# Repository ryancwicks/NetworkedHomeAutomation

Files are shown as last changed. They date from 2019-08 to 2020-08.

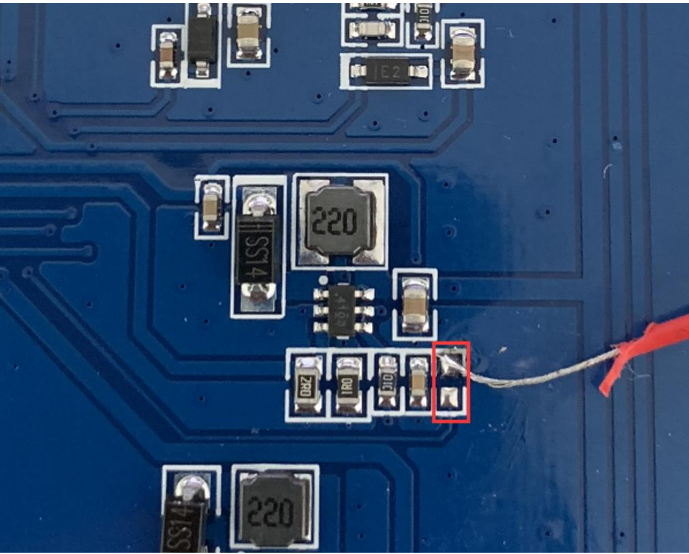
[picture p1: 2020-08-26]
images/waveshare-wire.png

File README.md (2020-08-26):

# Networked Home Automation

The repo contains all the setup files for a networked home automation system based on ESPHome, Node Red and a mix of networked switches and custom firmware.

The MQTT broker and NodeRed server run on a raspberry Pi Zero W (set up with Docker).

## Raspberry Pi Setup

The system has been set up using a Raspberry Pi B+. The Raspberry Pi OS Lite was used as the base. A 7" Waveshare LCD with a capacitive touch screen is used as the main interface.

Start raspi-config, set up the wifi, change the keyboard layout and setup openssh.

I set up the user using this page: 

https://www.raspberrypi.org/documentation/configuration/security.md

I also added a lxde:

https://raspberrytips.com/upgrade-raspbian-lite-to-desktop/

In raspi-config, set the system to autologin the gui.

The final piece to add is an install of Chromium. The current version of Firefox in the apt packages doesn't support kiosk mode.

```
sudo apt install chromium
```

Copy the script run_chrome_kiosk.sh to /home/<user> and set it executable.

Copy the node-mosquitto-service.service file to /etc/systemd/system

Copy the autostart file to ~/.config/lxsession/LXDE

Copy the contents of the nodeRED directory to the ~/docker-compose directory.

Install docker: 

```
curl -sSL https://get.docker.com | sh
sudo usermod -aG docker pi 
```

Reboot here, and then test docker:

```
docker run hello-world --rm
```

```
sudo apt-get install -y libffi-dev libssl-dev
sudo apt-get install -y python3 python3-pip
sudo apt-get remove python-configparser
```

setup docker compose:

```
sudo pip3 -v install docker-compose 
```

I also installed log2ram to prevent SD card wear:

https://mcuoneclipse.com/2019/04/01/log2ram-extending-sd-card-lifetime-for-raspberry-pi-lorawan-gateway/

Set up the gui to auto login under the system preference.

Set the screensaver to return a black screen after 1 minute.

## Resolution very low

Edit the /boot/config.txt file and ensure the following is set.

max_usb_current=1
hdmi_group=2
hdmi_mode=87
hdmi_cvt 1024 600 60 6 0 0 0
hdmi_drive=1

## Chrome doesn't work:

For some reason, I was getting an illegal instruction error when I tried to run chromium. Instead I installed Midori and changed the autostart command to 

```
midori -e Fullscreen -a http://google.com
```

## Set up the backlight:

This needs to be done manually. A wire needs to be run from Raspberry pi pin 20 to a SMD pad on the board.

The RPi pin is shown here:

![images/rpi-wire.png][RPi wire location]

The other end of the wire needs to be soldered here:

![images/waveshare-wire.png][Waveshare location]

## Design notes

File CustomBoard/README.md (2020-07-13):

# NetworkedHomeAutomation
Simple home automation setup using ESP32's as an MQTT client and a Raspberry Pi based MQTT broker.

# Testing the client:

Install the mosquitto app:

```bash
sudo snap install mosquitto
```

In one window, open the subscriber that listens for new devices:

```bash
mosquitto_sub -t "newDevice"
```

In another window, you can turn the device on and off with 

```bash
mosquitto_pub -t "LightSwitch/power" -m "1"
```

and

```bash
mosquitto_pub -t "lightSwitch/power" -m "0"
```

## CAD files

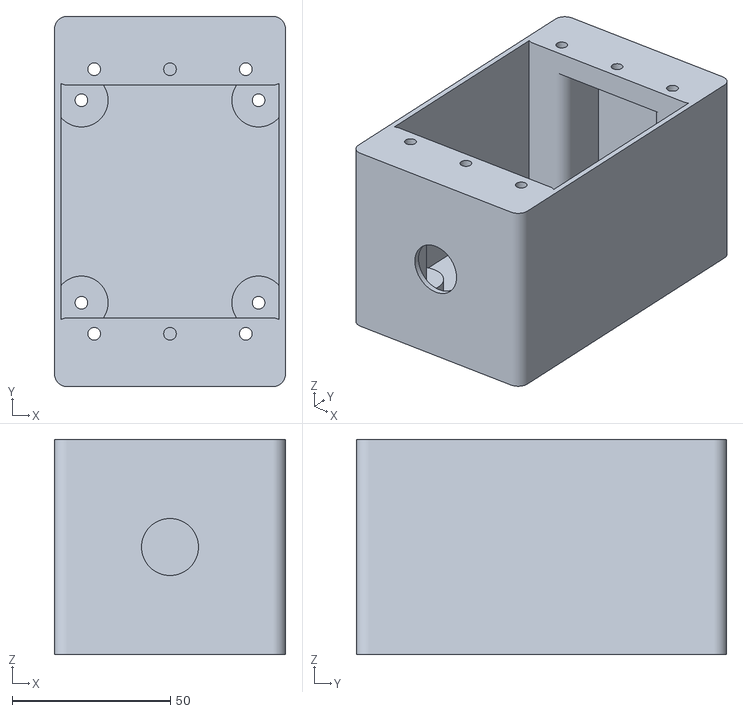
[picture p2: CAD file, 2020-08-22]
CustomBoard/PowerSwitchClient/HousingCAD/MainHousing.stl
73.0 x 117.0 x 68.0

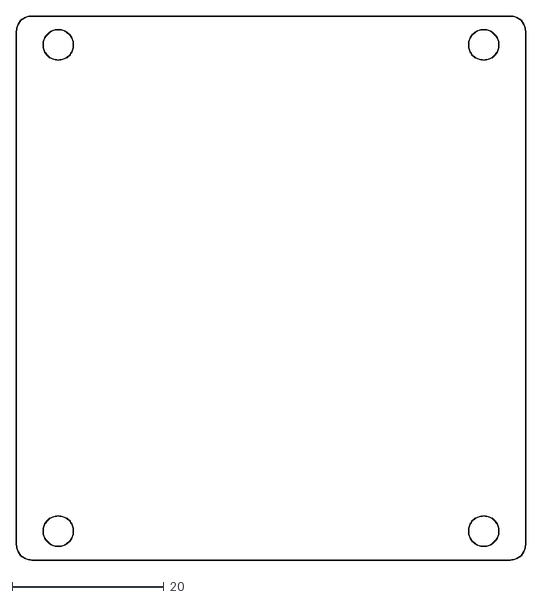
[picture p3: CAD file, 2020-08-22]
CustomBoard/PowerSwitchClient/HousingCAD/board_layout.dxf
67.0 x 71.6

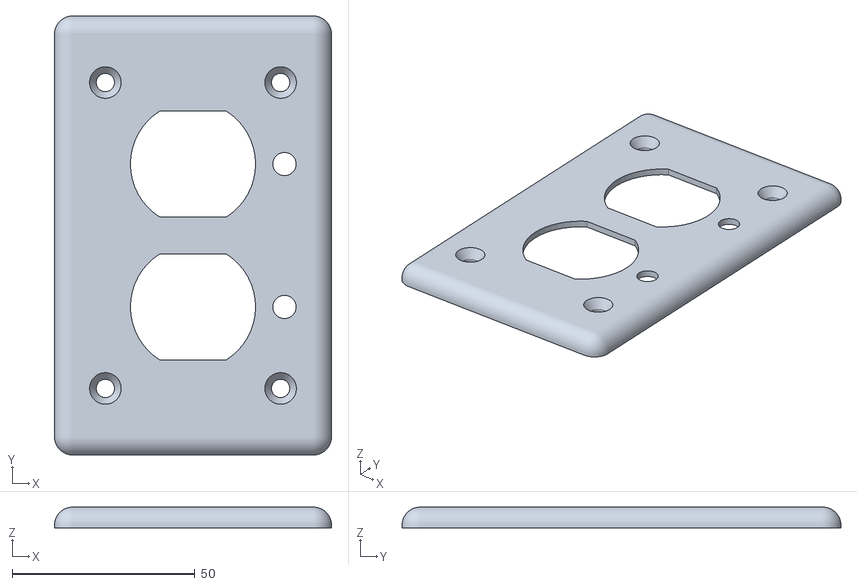
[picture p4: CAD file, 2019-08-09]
CustomBoard/PowerSwitchClient/HousingCAD/CoverPlate.stl
75.8 x 120.0 x 5.69

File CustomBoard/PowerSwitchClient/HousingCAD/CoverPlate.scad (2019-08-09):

$fn=50;

module screw_hole (height=1000) {
    diameter= 5;
    diameter_top = 8.7;
    union(){
        cylinder(r=diameter/2, h=height);
        cylinder(h=3, r1=diameter_top/2, r2=diameter/2);
    };
};

module base_plate () {
    width_total = 75.75;
    height_total = 120;
    thickness_total = 5.7;
    corner_radius = 5;
    back_inset_depth = 1.2;
    full_inset_depth = 2.5;
    clearance_hole_depth = full_inset_depth + 1.75;
    
    difference() {
        //main_body
       minkowski() {
           cube([width_total-2*corner_radius, height_total-2*corner_radius, 2*thickness_total-2*corner_radius], center=true);
           sphere(r=corner_radius, center=true);
       };
       
       //remove half of box
       translate([0, 0, -thickness_total]) cube([width_total, height_total,    thickness_total*2], center=true);
       
       //remove first inner layer (box rests on this surface
       translate([-(width_total-2 - corner_radius)/2, -(height_total- 2 - corner_radius)/2, -back_inset_depth/2]) minkowski() {
            cube([width_total - 2 - corner_radius, height_total - 2- corner_radius, back_inset_depth]);
            cylinder(r=corner_radius/2, h=back_inset_depth);
        };
        
        //remove inner layer (clearance for plug  components
       translate([-(width_total-5.2 - corner_radius)/2, -(height_total- 5.2 - corner_radius)/2, -full_inset_depth/2]) minkowski() {
           cube([width_total - 5.2 - corner_radius, height_total - 5.2- corner_radius, full_inset_depth]);
           cylinder(r=corner_radius/2, h=full_inset_depth);
       };
    };
    
    
};

module plug_hole(thickness) {
    height=29;
    diameter=34.2;
    
    difference() {
        cylinder(r=diameter/2, h=thickness, center=true);
        translate([0, height, 0]) cube([diameter, height, thickness], center=true);
        translate([0, -height, 0]) cube([diameter, height, thickness], center=true);
    };
};


led_hole = 6.35;
plate_hole_position = (10.1 + 68.0) / 4;
lateral_hole_position = (43 + 52.8)/4;
vertical_hole_position = (88.7 + 78.5)/4;
hole_positions = [ [lateral_hole_position, vertical_hole_position, 5.75], 
                  [-lateral_hole_position, vertical_hole_position, 5.75], 
                  [lateral_hole_position, -vertical_hole_position, 5.75], 
                  [-lateral_hole_position, -vertical_hole_position, 5.75] ];
difference() {
    union() {
        base_plate();
        for (pos = hole_positions) {
            translate([pos[0], pos[1],        
     1.3]) 
                cylinder(r=8.2/2, h=2*1.3);
        }
    };
    //socket holes
    translate([0, plate_hole_position, 0]) plug_hole(100);
    translate([0, -plate_hole_position, 0]) plug_hole(100);
    //led holes
    translate([25, plate_hole_position, 0]) cylinder(r=led_hole/2, h=100);
    translate([25, -plate_hole_position, 0]) cylinder(r=led_hole/2, h=100);
    for (pos = hole_positions) {
        translate(pos) rotate([180, 0, 0]) screw_hole();
        offset_pos = pos;
        //offset_pos[2] = 0.0012;
        translate(offset_pos) 
            cylinder(r=8.2, h=1.17);
    };
    for (pos = [[0, vertical_hole_position, 0], [0, -vertical_hole_position, 0]]) {
        translate (pos) cylinder(r=8.2/2, h=4.6);
    }
    
 };

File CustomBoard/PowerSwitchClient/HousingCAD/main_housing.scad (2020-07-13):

//**************************
// Defines
$fn=64;

width_total = 73;
height_total = 117;
thickness_total = 68;
wall_thickness = 4; //can fit an m6 machine nut

center= [width_total/2, height_total/2];

lateral_hole_position = (43 + 52.8)/4;
vertical_hole_position = (88.7 + 78.5)/4;

hole_positions = [ [lateral_hole_position + center[0], vertical_hole_position + center[1], 0], 
                  [-lateral_hole_position + center[0], vertical_hole_position + center[1], 0], 
                  [lateral_hole_position + center[0], -vertical_hole_position + center[1], 0], 
                  [-lateral_hole_position + center[0], -vertical_hole_position + center[1], 0] ];
   
board_xoff = 28;
board_yoff = 32;
board_hole_positions = [ [board_xoff + center[0], board_yoff + center[1], 0], 
                  [-board_xoff + center[0], board_yoff + center[1], 0], 
                  [board_xoff + center[0], -board_yoff + center[1], 0], 
                  [-board_xoff + center[0], -board_yoff + center[1], 0] ];
   
//Grommet clearance hole.
main_wire_hole_r = 18/2;

//For the #6 machine screws. May be different thread forms.
hole_clearance = 4/2;
nut_size = 5/16 * 25.4 + 0.5; 

//board_sizes
b_width = width_total - 2*wall_thickness +2 ;
b_height = height_total - 2*hole_positions[3][1] - 2*wall_thickness-4 ;

//***************************
// Actions
main_body();
//translate([width_total/2, height_total/2, 2*wall_thickness]) 
//projection(cut=true) 
//board();

//***************************
// Modules

module board() {
    board_thickness = 1.6;
    color ("green", 1)
    difference () {
        linear_extrude (board_thickness) offset(2) square ([b_width-4, b_height-4], center=true);
      
        //remove mounting holes and hex nuts
        for (i = board_hole_positions) {
            translate([-center[0], -center[1], 0]) translate (i) cylinder (r = hole_clearance, h = 10000, center = true);
        }  
    };
}

module main_body () {
    mounting_hole_extra = 5;
    
    difference() {
        union () {
            //base
            linear_extrude (height=wall_thickness) translate ([             wall_thickness, wall_thickness, 0 ]) offset (             wall_thickness ) square ([width_total - 2*             wall_thickness, height_total - 2*wall_thickness]);

            //wall
            linear_extrude (height=thickness_total)  
            difference () {
                translate ([ wall_thickness, wall_thickness, 0 ]) offset (              wall_thickness ) square ([width_total - 2*              wall_thickness, height_total - 2*wall_thickness]);
                translate ([ 3/2*wall_thickness, 3/2*wall_thickness, 0 ])              offset( wall_thickness ) square ([width_total - 3*              wall_thickness, height_total - 3*wall_thickness]);
            };
       
            //blocks for mounting holes.
            for (i = [[0, 0], 
                    [width_total - hole_positions[3][0] - mounting_hole_extra, 0],
                    [0, height_total-hole_positions[3][1]-mounting_hole_extra], 
                    [width_total - hole_positions[3][0]-mounting_hole_extra, height_total- hole_positions[3][1]- mounting_hole_extra]]) {
                translate([i[0], i[1], 0]) linear_extrude (height=              thickness_total) translate ([ wall_thickness,              wall_thickness, 0 ]) offset ( wall_thickness ) square              ([hole_positions[3][0] - 2*wall_thickness+mounting_hole_extra, hole_positions[3][1] - 2*wall_thickness + mounting_hole_extra]);
            };
            
            translate ([width_total/2, (hole_positions[3][1] + mounting_hole_extra)/2, thickness_total - wall_thickness]) cube ([width_total - hole_positions[3][0], hole_positions[3][1] + mounting_hole_extra, 2*wall_thickness], center=true);
            translate ([width_total/2, height_total - (hole_positions[3][1] + mounting_hole_extra)/2, thickness_total - wall_thickness]) cube ([width_total - hole_positions[3][0], hole_positions[3][1] + mounting_hole_extra, 2*wall_thickness], center=true);
            
            //board_mount_posts
            for (i = board_hole_positions) {
                translate (i) cylinder (r=nut_size, h=2*wall_thickness);
            }
         
        };
        
        //remove mounting holes and hex nuts
        for (i = hole_positions) {
            translate (i) cylinder (r = hole_clearance, h = 10000, center = true);
            translate ([0, 0, -1]) translate(i) hex_flat_to_flat (nut_size, 0.2, thickness_total-2*wall_thickness);
        }
        
        translate ([width_total/2, hole_positions[3][1], thickness_total]) cylinder (r=hole_clearance, h=4*wall_thickness+1, center=true);
        translate ([width_total/2, hole_positions[0][1], thickness_total]) cylinder (r=hole_clearance, h=4*wall_thickness+1, center=true);
        
        
        translate ([width_total/2, wall_thickness, thickness_total/2 ]) rotate (90, [1, 0, 0]) cylinder(r=main_wire_hole_r, h = 2*wall_thickness, center=true);
        
        //remove mounting holes
        for (i = board_hole_positions) {
                translate (i) cylinder (r=hole_clearance, h=10*wall_thickness);
                translate([i[0], i[1], -1]) hex_flat_to_flat(nut_size, 0.2, wall_thickness+1);
            }
    };
    
};

module hex_flat_to_flat ( distance, corner_radius, thickness ) {
    h = distance / 2;
    d = h/cos(30);
    hull () {
        for ( i = [0:60:359] ) {
            rotate(i, [0, 0, 1]) translate ([d-corner_radius, 0, 0]) cylinder (h=thickness, r = corner_radius);
        }
    }
};

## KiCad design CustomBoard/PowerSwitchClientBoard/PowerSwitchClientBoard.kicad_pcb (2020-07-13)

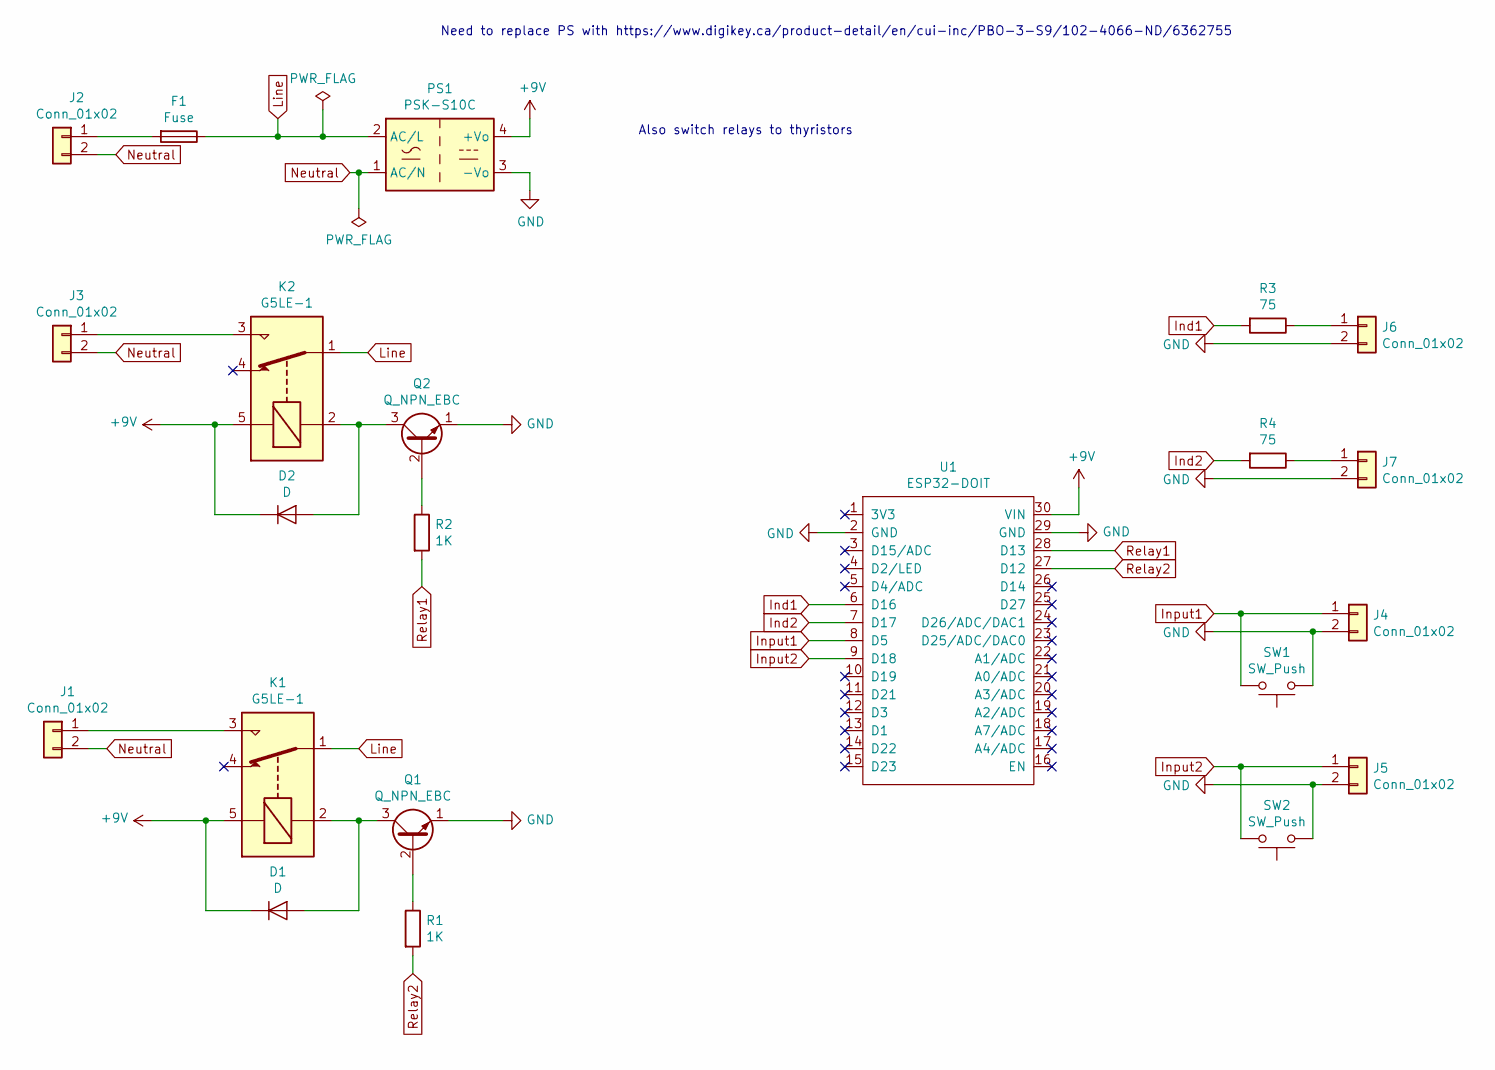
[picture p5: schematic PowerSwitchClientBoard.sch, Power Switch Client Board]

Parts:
D1, D2: D; D_DO-41_SOD81_P10.16mm_Horizontal; PartNumber 1N4007-TP
F1: Fuse; Fuseholder_Cylinder-5x20mm_Schurter_0031_8201_Horizontal_Op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; PartNumber Schurter 0031.8211
J1, J2, J3: Conn_01x02; SolderWirePad_1x02_P5.08mm_Drill1.5mm
J4, J5, J6, J7: Conn_01x02; PinHeader_1x02_P2.54mm_Vertical
K1, K2: G5LE-1; Relay_SPDT_Omron-G5LE-1; PartNumber G5LE-1 DC9
PS1: PSK-S10C
Q1, Q2: Q_NPN_EBC; TO-92_Inline; PartNumber PN2222ABU
R1, R2: 1K; R_Axial_DIN0207_L6.3mm_D2.5mm_P10.16mm_Horizontal; PartNumber RNF14FTD1K00
R3, R4: 75; R_Axial_DIN0207_L6.3mm_D2.5mm_P10.16mm_Horizontal; PartNumber RNF14FTD75R0
SW1, SW2: SW_Push; SW_Tactile_SKHH_Angled; PartNumber 1825027-8
U1: ESP32-DOIT; PartNumber ESP32-DOIT

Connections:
+9V: D1.1 (K), D2.1 (K), K1.5, K2.5, PS1.4 (+Vo), U1.30 (VIN)
GND: J4.2, J5.2, J6.2, J7.2, PS1.3 (-Vo), Q1.1 (E), Q2.1 (E), SW1.1, SW2.1, U1.2 (GND), U1.29 (GND)
Ind1: R3.2, U1.6 (D16)
Ind2: R4.2, U1.7 (D17)
Input1: J4.1, SW1.2, U1.8 (D5)
Input2: J5.1, SW2.2, U1.9 (D18)
Line: F1.1, K1.1, K2.1, PS1.2 (AC/L)
unnamed: D1.2 (A), K1.2, Q1.3 (C)
unnamed: D2.2 (A), K2.2, Q2.3 (C)
unnamed: F1.2, J2.1
unnamed: J1.1, K1.3
unnamed: J3.1, K2.3
unnamed: J6.1, R3.1
unnamed: J7.1, R4.1
unnamed: Q1.2 (B), R1.1
unnamed: Q2.2 (B), R2.1
Neutral: J1.2, J2.2, J3.2, PS1.1 (AC/N)
Relay1: R2.2, U1.28 (D13)
Relay2: R1.2, U1.27 (D12)

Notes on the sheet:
Need to replace PS with https://www.digikey.ca/product-detail/en/cui-inc/PBO-3-S9/102-4066-ND/6362755
Also switch relays to thyristors

Board: 2 copper layers, 22 parts (1 on the bottom side), 19 nets, no tracks yet.

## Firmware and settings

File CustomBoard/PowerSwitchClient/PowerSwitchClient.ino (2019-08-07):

/**
 * This program recieves requests to turn on and off a relay through MQTT.
 */

#include <WiFi.h>
#include <PubSubClient.h>
#include <EEPROM.h>
#include <WebServer.h>

//SoftAP settings for initial setup
const char * default_SSID = "LightSwitch";
const char * default_password = "setuplight";

//Web server for setting SSID, Password and MQTT broker
WebServer server(80);
#include "web_pages.h"

//Persistently stored SSID, password and MQTT broker IP
const unsigned int SSID_OFFSET = 0;
const unsigned int SSID_SIZE = 50;
const unsigned int PASSWORD_OFFSET = SSID_OFFSET + SSID_SIZE;
const unsigned int PASSWORD_SIZE = 150;
const unsigned int BROKER_IP_OFFSET = PASSWORD_OFFSET + PASSWORD_SIZE;
const unsigned int BROKER_IP_SIZE = 16;

char SSID[SSID_SIZE] = {0};
char password[PASSWORD_SIZE] = {0};
char broker_ip[BROKER_IP_SIZE] = {0};

//MQTT settings
unsigned int port = 1883;
unsigned int baudrate = 115200;
const char * clientName = "LightSwitch";

//Hardware Settings
const unsigned int power_pin = 19;

WiFiClient wifiClient;
PubSubClient client(wifiClient);

void callback(char * topic, byte * payload, unsigned int length) {
  Serial.print ("Message recieved [");
  Serial.print (topic);
  Serial.print("] ");
  if (payload[0] == '0') {
    digitalWrite (power_pin, LOW);
    Serial.print (" Power Off.");
  } else {
    digitalWrite (power_pin, HIGH);
    Serial.print (" Power On.");
  }
  Serial.println();
}

void load_persistent() {
  unsigned int i = 0; 
  for (i = 0; i < SSID_SIZE; ++i) {
     SSID[i] = EEPROM.read(i + SSID_OFFSET);
  }
  for (i = 0; i < PASSWORD_SIZE; ++i) {
     password[i] = EEPROM.read(i+PASSWORD_OFFSET);
  }
  for (i = 0; i < BROKER_IP_SIZE; ++i) {
     broker_ip[i] = EEPROM.read(i+BROKER_IP_OFFSET);
  }
}

void save_persistent() {
  unsigned int i = 0; 
  for (i = 0; i < SSID_SIZE; ++i) {
     EEPROM.write(i + SSID_OFFSET, SSID[i]);
     EEPROM.commit();
  }
  for (i = 0; i < PASSWORD_SIZE; ++i) {
     EEPROM.write(i+PASSWORD_OFFSET, password[i]);
     EEPROM.commit();
  }
  for (i = 0; i < BROKER_IP_SIZE; ++i) {
     EEPROM.write(i+BROKER_IP_OFFSET, broker_ip[i]);
     EEPROM.commit();
  }
}

void reconnect() {
  //loop until reconnected
  while (!client.connected()) {
    Serial.print ("Attempting MQTT connection...");
    if (client.connect(clientName)) {
      Serial.println("connected");
      client.publish("newDevice", clientName );
      String subscribed_topic (clientName);
      subscribed_topic += "/power";
      client.subscribe(subscribed_topic.c_str());
    } else {
      Serial.print ("failed, rc=");
      Serial.print(client.state());
      Serial.println (" try again in 5 seconds.");
      delay(5000);
    }
  }
}

void setup() {
  pinMode (power_pin, OUTPUT);
  digitalWrite (power_pin, LOW);
  
    Serial.begin(baudrate);
    delay(10);

  if (false) {
    WiFi.softAP(default_SSID, default_password);
 
    Serial.println();
    Serial.print("IP address: ");
    Serial.println(WiFi.softAPIP());
 
  } else {
    client.setServer (broker_ip, port);
    client.setCallback(callback);
  
    Serial.println();
    Serial.println();
    Serial.print("Connecting to ");
    Serial.println(SSID);

    WiFi.begin(SSID, password);

    while (WiFi.status() != WL_CONNECTED) {
        delay(500);
        Serial.print(".");
    }

    Serial.println("");
    Serial.println("WiFi connected");
    Serial.println("IP address: ");
    Serial.println(WiFi.localIP());
  }
  server.on("/", [](){
    server.send(200, "text/plain", "Hello World");
  });
 
  server.begin();   
}

void loop() {
  if (!client.connected()) {
    reconnect();
    server.handleClient();
  }
  client.loop();
}

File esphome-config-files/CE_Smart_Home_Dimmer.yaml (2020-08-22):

esphome:
  name: ce_smart_home_dimmer_1
  platform: ESP8266
  board: esp8285
  arduino_version: 2.4.2

wifi:
  ssid: !secret wifi_ssid
  password: !secret wifi_password

#api:

logger:
  baud_rate: 0

ota:
  password: !secret ota_password

web_server: 
  port: 80

mqtt:
  broker: !secret mqtt_broker
  #username: !secret mqtt_username
  #password: !secret mqtt_password
  port: !secret mqtt_port
  # Set to true when finished testing to set MQTT retain flag
  discovery_retain: false
  birth_message:
    topic: ce_smart_home_dimmer_1/status
    payload: online
  will_message:
    topic: CE_smart_home_dimmer_1/status
    payload: offline

# My dimmer used the hardware serial port on the alternate pins
uart:
  rx_pin: GPIO13
  tx_pin: GPIO15
  baud_rate: 9600

# Register the Tuya MCU connection
tuya:

# Create a light using the dimmer
light:
  - platform: "tuya"
    name: "dim1"
    dimmer_datapoint: 3
    switch_datapoint: 1
    min_value: 0
    max_value: 255

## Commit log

2019-08-07 Started work on mechanical and electrical. software not currently working.
    [CoverPlate.scad, CoverPlate.stl, PowerSwitchClientBoard.kicad_pcb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]
2019-08-09 Started some cad work.
    [CoverPlate.scad, CoverPlate.stl, PowerSwitchClientBoard.kicad_pcb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]
2020-07-13 WIP, got docker node/mqtt server working, can't get esphome devices to connect to it through mqtt.
    [CoverPlate.scad, CoverPlate.stl, PowerSwitchClientBoard.kicad_pcb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]
2020-08-22 Working on Raspberry pi. Need to add setup instructions.
    [MainHousing.stl, board_layout.dxf]
